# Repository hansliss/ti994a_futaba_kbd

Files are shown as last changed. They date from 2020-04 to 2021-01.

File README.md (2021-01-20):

# ti994a_futaba_kbd
A Futaba MD PCB for TI-99/4a

Included is also a simple Arduino sketch for testing the keyboard. Connect the rows (pin 8,13,14,15,9,12 on the connector) to port C, the columns (pin 5, 4, 1, 2, 11, 3, 10, 7 on the connector) to port A, and pin 6 on the connector (ALPHA LOCK) to A0. You may have to experiment with the pin numbering; I can't verify the order.

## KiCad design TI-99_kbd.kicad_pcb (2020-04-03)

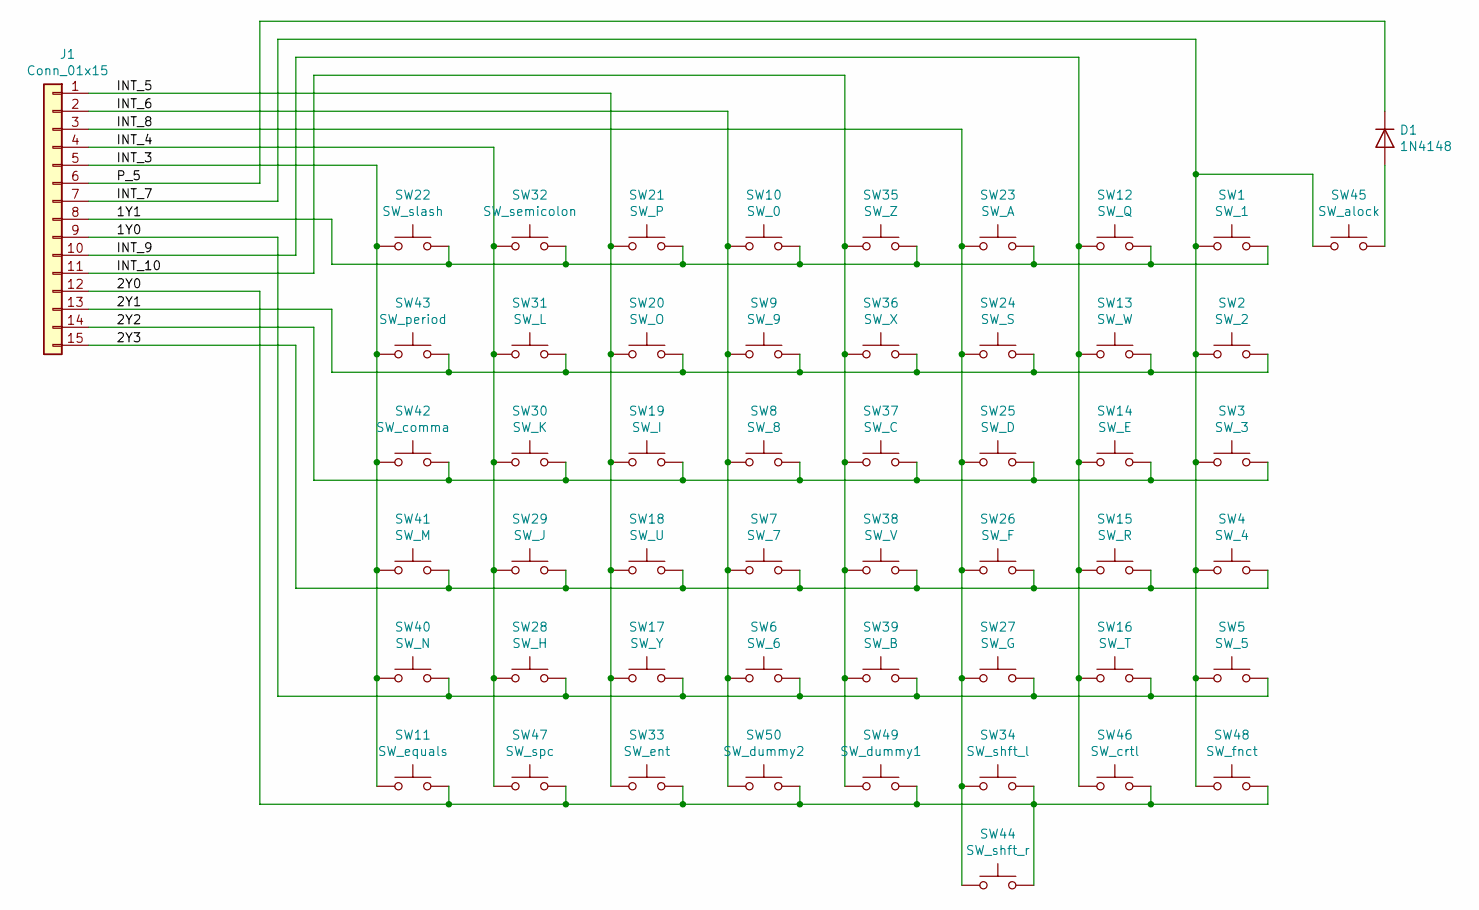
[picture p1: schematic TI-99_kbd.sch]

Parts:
D1: 1N4148; D_DO-35_SOD27_P7.62mm_Horizontal
J1: Conn_01x15; Pin_Header_Straight_1x15_Pitch2.54mm
SW1: SW_1; Futaba_MD_keyswitch
SW2: SW_2; Futaba_MD_keyswitch
SW3: SW_3; Futaba_MD_keyswitch
SW4: SW_4; Futaba_MD_keyswitch
SW5: SW_5; Futaba_MD_keyswitch
SW6: SW_6; Futaba_MD_keyswitch
SW7: SW_7; Futaba_MD_keyswitch
SW8: SW_8; Futaba_MD_keyswitch
SW9: SW_9; Futaba_MD_keyswitch
SW10: SW_0; Futaba_MD_keyswitch
SW11: SW_equals; Futaba_MD_keyswitch
SW12: SW_Q; Futaba_MD_keyswitch
SW13: SW_W; Futaba_MD_keyswitch
SW14: SW_E; Futaba_MD_keyswitch
SW15: SW_R; Futaba_MD_keyswitch
SW16: SW_T; Futaba_MD_keyswitch
SW17: SW_Y; Futaba_MD_keyswitch
SW18: SW_U; Futaba_MD_keyswitch
SW19: SW_I; Futaba_MD_keyswitch
SW20: SW_O; Futaba_MD_keyswitch
SW21: SW_P; Futaba_MD_keyswitch
SW22: SW_slash; Futaba_MD_keyswitch
SW23: SW_A; Futaba_MD_keyswitch
SW24: SW_S; Futaba_MD_keyswitch
SW25: SW_D; Futaba_MD_keyswitch
SW26: SW_F; Futaba_MD_keyswitch
SW27: SW_G; Futaba_MD_keyswitch
SW28: SW_H; Futaba_MD_keyswitch
SW29: SW_J; Futaba_MD_keyswitch
SW30: SW_K; Futaba_MD_keyswitch
SW31: SW_L; Futaba_MD_keyswitch
SW32: SW_semicolon; Futaba_MD_keyswitch
SW33: SW_ent; Futaba_MD_keyswitch
SW34: SW_shft_l; Futaba_MD_keyswitch
SW35: SW_Z; Futaba_MD_keyswitch
SW36: SW_X; Futaba_MD_keyswitch
SW37: SW_C; Futaba_MD_keyswitch
SW38: SW_V; Futaba_MD_keyswitch
SW39: SW_B; Futaba_MD_keyswitch
SW40: SW_N; Futaba_MD_keyswitch
SW41: SW_M; Futaba_MD_keyswitch
SW42: SW_comma; Futaba_MD_keyswitch
SW43: SW_period; Futaba_MD_keyswitch
SW44: SW_shft_r; Futaba_MD_keyswitch
SW45: SW_alock; Futaba_MD_keyswitch
SW46: SW_crtl; Futaba_MD_keyswitch
SW47: SW_spc; Futaba_MD_keyswitch
SW48: SW_fnct; Futaba_MD_keyswitch
SW49: SW_dummy1; SW_PUSH_6mm_h4.3mm
SW50: SW_dummy2; SW_PUSH_6mm_h4.3mm

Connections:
/1Y0: J1.9, SW5.2, SW6.2, SW16.2, SW17.2, SW27.2, SW28.2, SW39.2, SW40.2
/1Y1: J1.8, SW1.2, SW10.2, SW12.2, SW21.2, SW22.2, SW23.2, SW32.2, SW35.2
/2Y0: J1.12, SW11.2, SW33.2, SW34.2, SW44.2, SW46.2, SW47.2, SW48.2, SW49.2, SW50.2
/2Y1: J1.13, SW2.2, SW9.2, SW13.2, SW20.2, SW24.2, SW31.2, SW36.2, SW43.2
/2Y2: J1.14, SW3.2, SW8.2, SW14.2, SW19.2, SW25.2, SW30.2, SW37.2, SW42.2
/2Y3: J1.15, SW4.2, SW7.2, SW15.2, SW18.2, SW26.2, SW29.2, SW38.2, SW41.2
/INT_3: J1.5, SW11.1, SW22.1, SW40.1, SW41.1, SW42.1, SW43.1
/INT_4: J1.4, SW28.1, SW29.1, SW30.1, SW31.1, SW32.1, SW47.1
/INT_5: J1.1, SW17.1, SW18.1, SW19.1, SW20.1, SW21.1, SW33.1
/INT_6: J1.2, SW6.1, SW7.1, SW8.1, SW9.1, SW10.1, SW50.1
/INT_7: J1.7, SW1.1, SW2.1, SW3.1, SW4.1, SW5.1, SW45.1, SW48.1
/INT_8: J1.3, SW23.1, SW24.1, SW25.1, SW26.1, SW27.1, SW34.1, SW44.1
/INT_9: J1.10, SW12.1, SW13.1, SW14.1, SW15.1, SW16.1, SW46.1
/INT_10: J1.11, SW35.1, SW36.1, SW37.1, SW38.1, SW39.1, SW49.1
/P_5: D1.1 (K), J1.6
unnamed: D1.2 (A), SW45.2

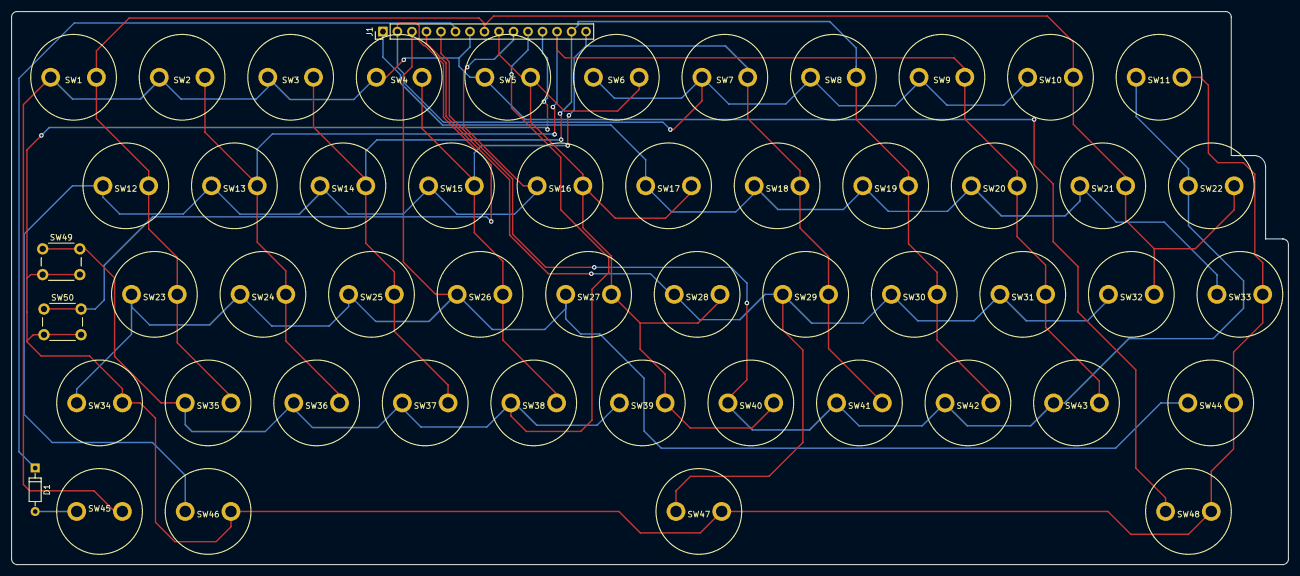
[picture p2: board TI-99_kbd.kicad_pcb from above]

Board: 2 copper layers, 223.5 x 96.8 mm, 52 parts (0 on the bottom side), 16 nets.

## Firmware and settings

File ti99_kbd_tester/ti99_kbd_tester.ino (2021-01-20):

#define COLS PORTA
#define COLSD DDRA

#define ROWS PINC
#define ROWSD DDRC

#define ALOCK A0

char *keyMatrix[6][8] = {
  {"\\", ";", "P", "0", "Z", "A", "Q", "1"},
  {".", "L", "O", "9", "X", "S", "W", "2"},
  {",", "K", "I", "8", "C", "D", "E", "3"},
  {"M", "J", "U", "7", "V", "F", "R", "4"},
  {"N", "H", "Y", "6", "B", "G", "T", "5"},
  {"=", "SPC", "ENT", "DUM1", "DUM2", "SHIFT", "CRTL", "FNCT"}
};

int keystate[6][8];

int alockState = 0;

void setup() {
  // put your setup code here, to run once:
  pinMode(ALOCK, INPUT);
  COLSD = B11111111;
  ROWSD = (ROWSD & ~B00111111);
  ROWS |= B00111111;
  for (int i=0; i< 8; i++) {
    for (int j=0; j<6; j++) {
      keystate[j][i] = 0;
    }
  }
  Serial.begin(9600);
}

void loop() {
  for (int i=0; i < 8; i++) {
    COLS = ~(1 << i);
    //delay(100);
    if (i == 1) {
      if (digitalRead(ALOCK) == HIGH) {
        if (!alockState) {
          Serial.println("ALOCK down");
          alockState = 1;
        }
      } else {
        if (alockState) {
          Serial.println("ALOCK up");
          alockState = 0;
        }
      }
    }
    //Serial.println(String(i, HEX) + ":" + String(~((unsigned char)(ROWS & B00111111)), HEX));
    for (int j=0; j<6; j++) {
      if (!(ROWS & (1 << j))) {
        if (!keystate[5-j][7-i]) {
          Serial.print(keyMatrix[5-j][7-i]);
          Serial.println(" down");
          keystate[5-j][7-i] = 1;
        }
      } else {
        if (keystate[5-j][7-i]) {
          Serial.print(keyMatrix[5-j][7-i]);
          Serial.println(" up");
          keystate[5-j][7-i] = 0;
        }
      }
    }
  }
  delay(10);
}

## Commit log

2020-04-03 Initial import
    [TI-99_kbd.kicad_pcb, TI-99_kbd.sch]
2020-04-03 Removed Gerber archive; added Gerber files
    [TI-99_kbd-B_Cu.gbr, TI-99_kbd-B_Mask.gbr, TI-99_kbd-B_Paste.gbr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]
2021-01-20 Added primitive Arduino code for testing.
2021-01-20 Updated readme with Arduino sketch info
